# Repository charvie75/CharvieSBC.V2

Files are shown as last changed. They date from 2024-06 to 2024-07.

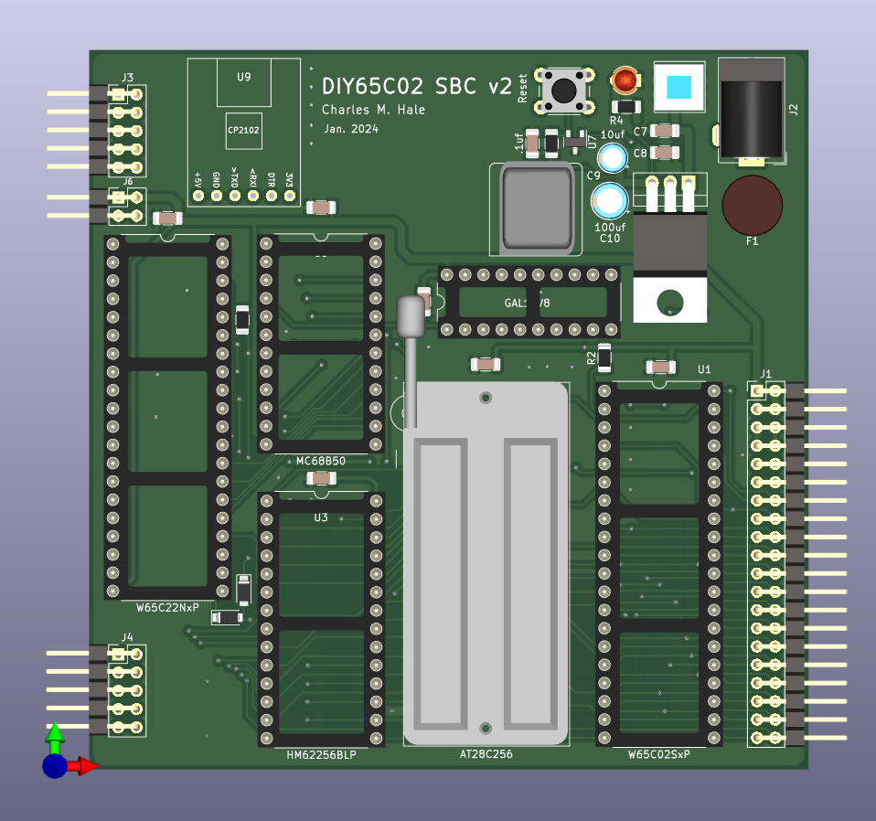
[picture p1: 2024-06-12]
KiCad.V6/DIY65C02.V2.CPU.Board.png

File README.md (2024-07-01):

# CharvieSBC.V2

This project was inspired by Ben Eater's YOUTUBE series. I, like many others, started my computer experience with the 6502 based computers.

Where this board differs from Ben's breadboard computer is that I use a GAL16V8D for the decode logic, a MC68B50 for an ACIA, a 1.8432Mhz osc for the cpu clock and baud rate generation and a CP2102 Micro USB to Serial adapter for terminal connection.

I also use a MCP130-450 power supervisor for the reset circuit. This allows for 'clean' 'no bounce' resets. It will also put the 65C02 in reset if Vcc falls below +4.35v.

The ACIA runs at 115200 baud.

If the LM7805 is used the input power can be either +9vdc or +12vdc. If you use a +5vdc source don't install the LM7805, just put a jumper between the pin 1 and 3.

Using the GAL16V8D ic allows flexible decoding. Coding of the GAL16V8D was done via WinCupl.

The memory map created by the .jed file is as follows.

C000 - FFFF ==> ROM.

9000 - BFFF ==> Not Used.

8000 - 8FFF ==> Hardware.

8008 & 8009 ==> ACIA.

8010 - 801F ==> VIA.

0000 - 7FFF ==> RAM.

I have developed a basic OS.
There are two versions of the OS. One can be loaded into a 16k EEROM. It does not have ehbasic.
The other is loaded into a 32k EEROM and does include a version of ehbasic.

The KERNAL is run at power up or reset.  It test RAM and writes the startup meeages to the terminal.  Most of these startup routines were borrowed and modified from VIC20 code.  It also includes a few usful routines that can be used when writing code.

ILOAD is an Intel HEX loader program that I 'borrowed' from D. Hansel's smon.asm files.
(https://github.com/dhansel/smon6502)
This allows code to be loaded into RAM and exit directly into WOZMON. Then using the WOZMON 'R' command the code can be run.

ClearRAM just writes $00 to all RAM locations from $0400 to $7FFF.

WOZMON is modified to show 16 values per line instead of 8.  the echo feature is removed and the kernal RXCHAR routine is used in it's place.

If there are any questions I can be reached at the following email address: charvie7190@gmail.com.

01 Jul 2024.......Added 'IRQ' Handler w/ interrupt vector (IRQ_VEC) @ $0314 & $0315

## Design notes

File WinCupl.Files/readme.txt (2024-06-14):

This folder contains the .jed file that is needed to program the GAL16V8 ic 
that is used for decoding and enabling the ROM, RAM, ACIA and VIA.

The memory map created by this .jed file is as follows:
	C000 - FFFF ==> ROM
	9000 - BFFF ==> Not Used
	8000 - 8FFF ==> Hardware
			8008 & 8009 ==> ACIA
			8010 - 801F ==> VIA
	0000 - 7FFF ==> RAM
	
The GAL .jed file coding was created using WinCupl.

Using the GAL ic reduces the chip count and adds flexablity to the project.  
GALs can be added to extension boards for further decoding needs.

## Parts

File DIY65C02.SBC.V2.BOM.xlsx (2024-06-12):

Project: DIY65C02 SBC v2
Developer: Charles M. Hale
Component Count: 37
Individual Components:
Item | Value | Description | FootPrint | Type/Size
C1 | .1uf | Capacitor | SMD | 1206
C2 | .1uf | Capacitor | SMD | 1206
C3 | .1uf | Capacitor | SMD | 1206
C4 | .1uf | Capacitor | SMD | 1206
C5 | .1uf | Capacitor | SMD | 1206
C6 | .1uf | Capacitor | SMD | 1206
C7 | .47uf | Capacitor | SMD | 1206
C8 | .1uf | Capacitor | SMD | 1206
C9 | 10uf | Capacitor | Electrolytic | Radial
C10 | 100uf | Capacitor | Electrolytic | Radial
C11 | .1uf | Capacitor | SMD | 1206
D1 | 1N4148 | Diode | SMD | 1206
D2 | 1N4148 | Diode | SMD | 1206
D3 | LED_RED | Diode | THT | 3.0mm
F1 | 1.5A | Fuse | THT | Radial
J1 |  | Conn_02x20 |  | PinHeader/2.54mm
J2 |  | Conn_Power |  | Barrel Jack
J3 |  | Conn_02x05 |  | PinHeader/2.54mm
J4 |  | Conn_02x05 |  | PinHeader/2.54mm
J6 |  | Conn_02x02 |  | PinHeader/2.54mm
R1 | 330 | Resistor | SMD | 1206
R2 | 4R7 | Resistor | SMD | 1206
R3 | 4R7 | Resistor | SMD | 1206
R4 | 1K | Resistor | SMD | 1206
SW1 | Reset | Push_Button | THT | Tactile/6x6mm
SW2 | Power | Push_Button | THT | DPDT/7x7mm | Self locking, 2mm pin spacing
U1 | W65C02 or R65C02 | Microprocessor | THT | 40 Pin DIP
U2 | AT28C256 | EEROM Memory | THT | 32 Pin DIP
U3 | HM62256 | SRAM Memory | THT | 32 Pin DIP
U4 | W65C22 | VIA | THT | 40 Pin DIP
U5 | MC68B50 | ACIA | THT | 24 Pin DIP
U6 | GAL16V8D | Logic Array | THT | 20 Pin DIP
U7 | MCP130T-450I/TT | Power_Supervisor | SMD | SOT-23-3 | 579-MCP130T-450I/TT
U8 | LM7805 | Regulator_+5v | THT | TO220/3 Pin
U9 | CP2102 | Serial-USB Adapter | THT | 6 Pin SIP | CP2102 MICRO USB to UART TTL
X1 | 1.8432Mhz | Oscillator | THT | 8 Pin DIP | ECS-2100AX-1.8432MHZ
ZIF | ZIF Socket | Socket | THT | 32 Pin DIP

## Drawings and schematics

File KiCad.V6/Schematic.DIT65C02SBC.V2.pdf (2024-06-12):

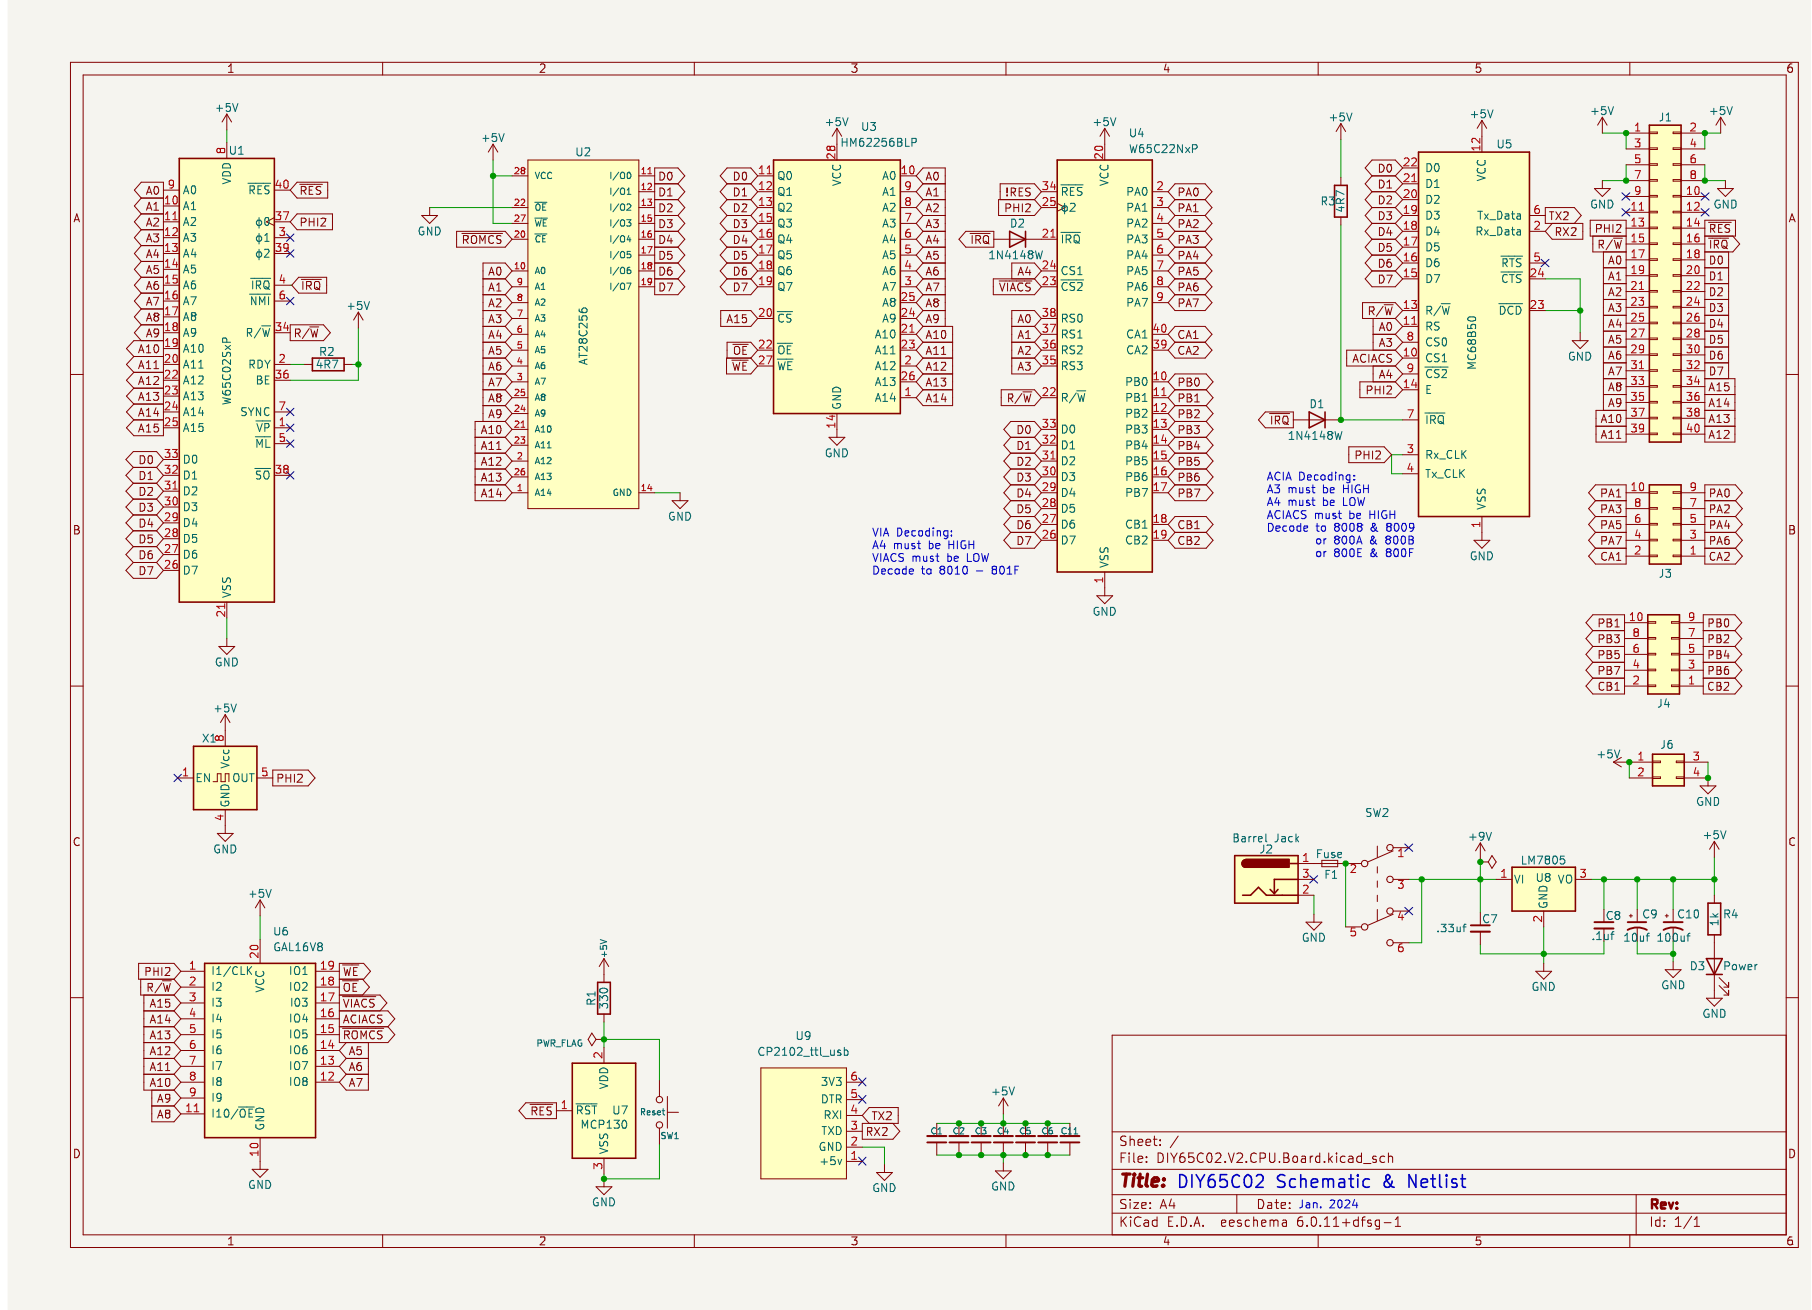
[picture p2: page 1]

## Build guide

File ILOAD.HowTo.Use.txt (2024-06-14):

ILOAD - How to use it.
	NOTE: For a terminal, I use 'PuTTY' with the connection set to 115200 baud, 8-1-N.
	Cursor is set to 'underline' (_).

1. Write the code that you want to develop/test.

2. Assemble the code into 'Intel HEX' format. To accomplish this step I use VASM with the following command line:
		vasm6502_oldstyle -dotdir -Fihex <file name>

This will creat a 'a.out' file that is NOT a bin file.

3. Open the file in a text editor. It should look similar to the following:

:1D700000A2FF2054F1E82042F19D0004C90DF007C918D0F14C00FF205FF14C0570A6
:00000001FF

	Can be multiple lines depending on the size of your code.

4. Copy this like you would copy lines of text that you intend to paste into another text file.

5. In the terminal press 'L' for LOAD. you will see a '.' and the cursor on the next line.

6. Move the mouse cursor (arrow) over the terminal cursor and press the scroll wheel down. 
This should paste the Intel HEX file into RAM. 
The terminal screen should look similar to the following:

.
:1D700000A2FF2054F1E82042F19D0004C90DF007C918D0F14C00FF205FF14C0570A6
:00000001FF
+
_

The '+' means that the file was loaded into RAM successfully. 
Press enter (return) on your keyboard and the terminal screen will clear 
and you will be left with the 'WOZMON' prompt '/' and the terminal cursor on the next line.

7. Enter the RAM memory location for the start of your code followed by '.R' and 'enter'. <XXXX.R> Your code should run.

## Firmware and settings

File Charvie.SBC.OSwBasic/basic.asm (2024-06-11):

; Enhanced BASIC to assemble under 6502 cODE $ver 2.22

; $E7E1 $E7CF $E7C6 $E7D3 $E7D1 $E7D5 $E7CF $E81E $E825

; 2.00	new revision numbers start here
; 2.01	fixed LCASE$() and UCASE$()
; 2.02	new get value routine done
; 2.03	changed RND() to galoise method
; 2.04	fixed SPC()
; 2.05	new get value routine fixed
; 2.06	changed USR() code
; 2.07	fixed STR$()
; 2.08	changed INPUT and READ to remove need for $00 start to input buffer
; 2.09	fixed RND()
; 2.10	integrated missed changes from an earlier version
; 2.20	added ELSE to IF .. THEN and fixed IF .. GOTO <statement> to cause error
; 2.21	fixed IF .. THEN RETURN to not cause error
; 2.22	fixed RND() breaking the get byte routine

; zero page use ..

LAB_WARM 		= $00	; BASIC warm start entry point
Wrmjpl 		= LAB_WARM+1; BASIC warm start vector jump low byte
Wrmjph 		= LAB_WARM+2; BASIC warm start vector jump high byte

Usrjmp		= $0A		; USR function JMP address
Usrjpl		= Usrjmp+1	; USR function JMP vector low byte
Usrjph		= Usrjmp+2	; USR function JMP vector high byte
Nullct		= $0D		; nulls output after each line
TPos			= $0E		; BASIC terminal position byte
TWidth		= $0F		; BASIC terminal width byte
Iclim			= $10		; input column limit
Itempl		= $11		; temporary integer low byte
Itemph		= Itempl+1	; temporary integer high byte

nums_1		= Itempl	; number to bin/hex string convert MSB
nums_2		= nums_1+1	; number to bin/hex string convert
nums_3		= nums_1+2	; number to bin/hex string convert LSB

Srchc			= $5B		; search character
Temp3			= Srchc	; temp byte used in number routines
Scnquo		= $5C		; scan-between-quotes flag
Asrch			= Scnquo	; alt search character

XOAw_l		= Srchc		; eXclusive OR, OR and AND word low byte
XOAw_h		= Scnquo	; eXclusive OR, OR and AND word high byte

Ibptr			= $5D	; input buffer pointer
Dimcnt		= Ibptr		; # of dimensions
Tindx			= Ibptr	; token index

Defdim		= $5E		; default DIM flag
Dtypef		= $5F		; data type flag, $FF=string, $00=numeric
Oquote		= $60		; open quote flag (b7) (Flag: DATA scan; LIST quote; memory)
Gclctd		= $60		; garbage collected flag
Sufnxf		= $61		; subscript/FNX flag, 1xxx xxx = FN(0xxx xxx)
Imode			= $62		; input mode flag, $00=INPUT, $80=READ

Cflag			= $63		; comparison evaluation flag

TabSiz		= $64		; TAB step size (was input flag)

next_s		= $65		; next descriptor stack address

					; these two bytes form a word pointer to the item
					; currently on top of the descriptor stack
last_sl		= $66		; last descriptor stack address low byte
last_sh		= $67		; last descriptor stack address high byte (always $00)

des_sk		= $68		; descriptor stack start address (temp strings)

;			= $70		; End of descriptor stack

ut1_pl		= $71		; utility pointer 1 low byte
ut1_ph		= ut1_pl+1	; utility pointer 1 high byte
ut2_pl		= $73		; utility pointer 2 low byte
ut2_ph		= ut2_pl+1	; utility pointer 2 high byte

Temp_2		= ut1_pl	; temp byte for block move	

FACt_1		= $75		; FAC temp mantissa1
FACt_2		= FACt_1+1	; FAC temp mantissa2
FACt_3		= FACt_2+1	; FAC temp mantissa3

dims_l		= FACt_2	; array dimension size low byte
dims_h		= FACt_3	; array dimension size high byte

TempB			= $78		; temp page 0 byte

Smeml			= $79		; start of mem low byte		(Start-of-Basic)
Smemh			= Smeml+1	; start of mem high byte	(Start-of-Basic)
Svarl			= $7B		; start of vars low byte	(Start-of-Variables)
Svarh			= Svarl+1	; start of vars high byte	(Start-of-Variables)
Sarryl		= $7D		; var mem end low byte		(Start-of-Arrays)
Sarryh		= Sarryl+1	; var mem end high byte		(Start-of-Arrays)
Earryl		= $7F		; array mem end low byte	(End-of-Arrays)
Earryh		= Earryl+1	; array mem end high byte	(End-of-Arrays)
Sstorl		= $81		; string storage low byte	(String storage (moving down))
Sstorh		= Sstorl+1	; string storage high byte	(String storage (moving down))
Sutill		= $83		; string utility ptr low byte
Sutilh		= Sutill+1	; string utility ptr high byte
Ememl			= $85		; end of mem low byte		(Limit-of-memory)
Ememh			= Ememl+1	; end of mem high byte		(Limit-of-memory)
Clinel		= $87		; current line low byte		(Basic line number)
Clineh		= Clinel+1	; current line high byte	(Basic line number)
Blinel		= $89		; break line low byte		(Previous Basic line number)
Blineh		= Blinel+1	; break line high byte		(Previous Basic line number)

Cpntrl		= $8B		; continue pointer low byte
Cpntrh		= Cpntrl+1	; continue pointer high byte

Dlinel		= $8D		; current DATA line low byte
Dlineh		= Dlinel+1	; current DATA line high byte

Dptrl			= $8F		; DATA pointer low byte
Dptrh			= Dptrl+1	; DATA pointer high byte

Rdptrl		= $91		; read pointer low byte
Rdptrh		= Rdptrl+1	; read pointer high byte

Varnm1		= $93		; current var name 1st byte
Varnm2		= Varnm1+1	; current var name 2nd byte

Cvaral		= $95		; current var address low byte
Cvarah		= Cvaral+1	; current var address high byte

Frnxtl		= $97		; var pointer for FOR/NEXT low byte
Frnxth		= Frnxtl+1	; var pointer for FOR/NEXT high byte

Tidx1			= Frnxtl	; temp line index

Lvarpl		= Frnxtl	; let var pointer low byte
Lvarph		= Frnxth	; let var pointer high byte

prstk			= $99		; precedence stacked flag

comp_f		= $9B		; compare function flag, bits 0,1 and 2 used
					; bit 2 set if >
					; bit 1 set if =
					; bit 0 set if <

func_l		= $9C		; function pointer low byte
func_h		= func_l+1	; function pointer high byte

garb_l		= func_l	; garbage collection working pointer low byte
garb_h		= func_h	; garbage collection working pointer high byte

des_2l		= $9E		; string descriptor_2 pointer low byte
des_2h		= des_2l+1	; string descriptor_2 pointer high byte

g_step		= $A0		; garbage collect step size

Fnxjmp		= $A1		; jump vector for functions
Fnxjpl		= Fnxjmp+1	; functions jump vector low byte
Fnxjph		= Fnxjmp+2	; functions jump vector high byte

g_indx		= Fnxjpl	; garbage collect temp index

FAC2_r		= $A3		; FAC2 rounding byte

Adatal		= $A4		; array data pointer low byte
Adatah		= Adatal+1	; array data pointer high  byte

Nbendl		= Adatal	; new block end pointer low byte
Nbendh		= Adatah	; new block end pointer high  byte

Obendl		= $A6		; old block end pointer low byte
Obendh		= Obendl+1	; old block end pointer high  byte

numexp		= $A8		; string to float number exponent count
expcnt		= $A9		; string to float exponent count

numbit		= numexp	; bit count for array element calculations

numdpf		= $AA		; string to float decimal point flag
expneg		= $AB		; string to float eval exponent -ve flag

Astrtl		= numdpf	; array start pointer low byte
Astrth		= expneg	; array start pointer high  byte

Histrl		= numdpf	; highest string low byte
Histrh		= expneg	; highest string high  byte

Baslnl		= numdpf	; BASIC search line pointer low byte
Baslnh		= expneg	; BASIC search line pointer high  byte

Fvar_l		= numdpf	; find/found variable pointer low byte
Fvar_h		= expneg	; find/found variable pointer high  byte

Ostrtl		= numdpf	; old block start pointer low byte
Ostrth		= expneg	; old block start pointer high  byte
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
